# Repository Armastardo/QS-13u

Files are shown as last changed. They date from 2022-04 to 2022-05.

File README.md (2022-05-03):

# QS-13u

Un teclado 40% de 13u, diseñado por Quark.Works, inspirado en el layout del Bacca40.

QS-13u render

## Layouts

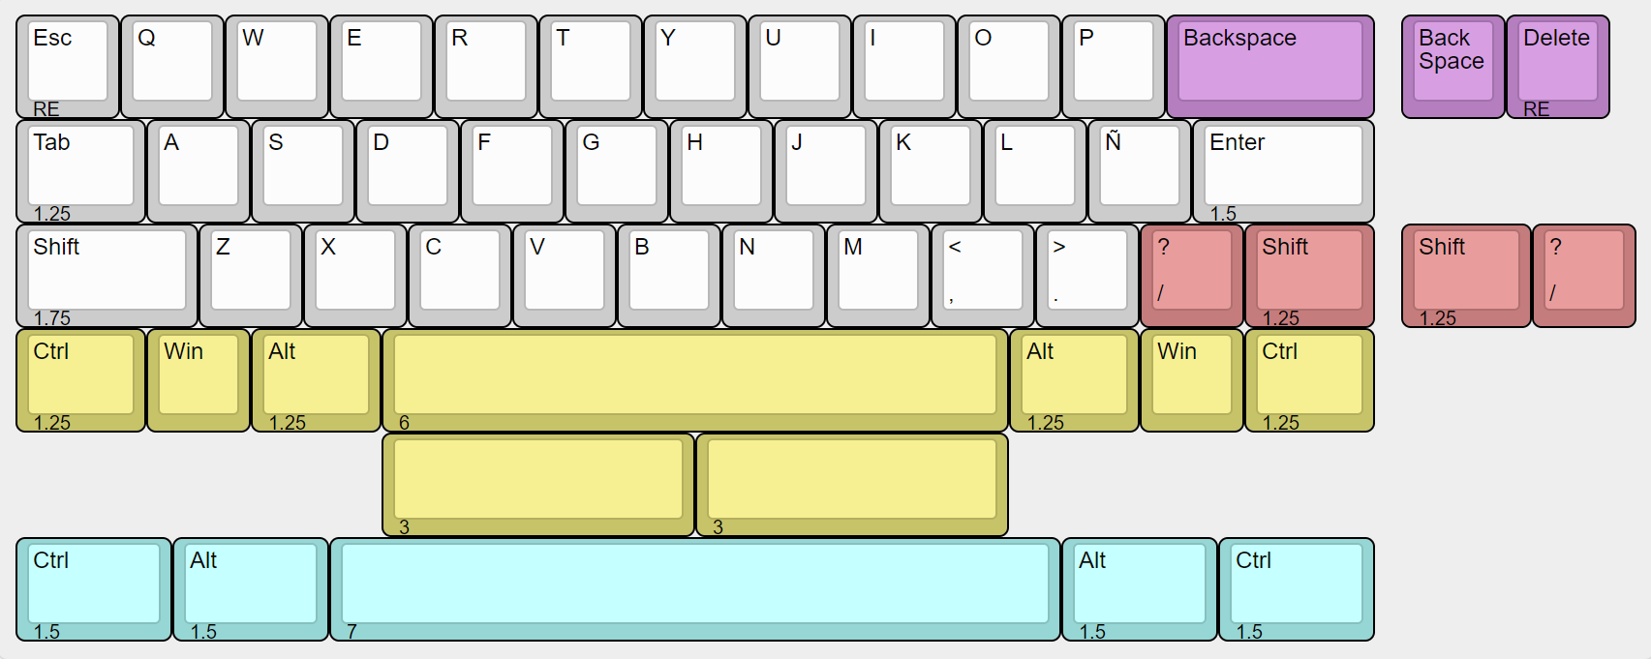
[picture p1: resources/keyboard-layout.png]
QS-13u layouts


[KLE Link](http://www.keyboard-layout-editor.com/#/gists/edd9330d8816866bf59f697946c975f9)

## Case

QS-13u render

QS-13u render

QS-13G (gummy worm)

Pendiente, buscar tamaño de oring adecuado

| Qty | Item						| Notes							|
|----:|---|---|
| 2	| Tornillo M2.5 x 4 mm						| https://www.mcmaster.com/91290A099/		|
| 4	| Tornillo M2.5 x 10 mm					| https://www.mcmaster.com/91290A103/		|
| 1	| XYZ Daughterboard			| https://github.com/xyzz/xyztkl-r2/tree/main/dboard	|

La version heatset ademas utiliza:
https://www.aliexpress.com/item/1005003174906572.html

| Qty | Item						|
|----:|---|
| 2	| Insert M2.5 x 3 x 3.5						|
| 4	| Insert M2.5 x 5 x 3.5					|

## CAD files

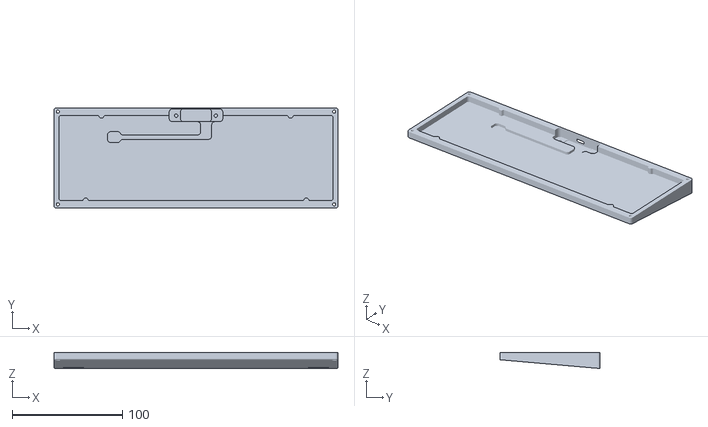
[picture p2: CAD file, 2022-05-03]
case/3d print/QS-13GT bottom heatset.stl
257.6 x 91.2 x 14.5

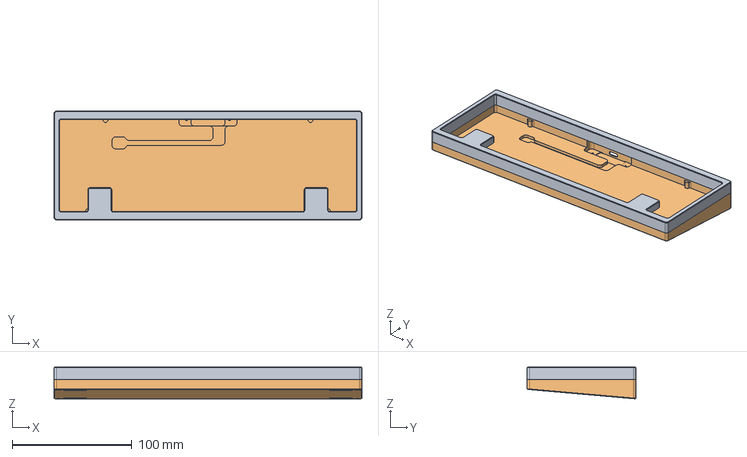
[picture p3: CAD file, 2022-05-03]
case/QS-13G.step
257.6 x 91.2 x 26.5 mm

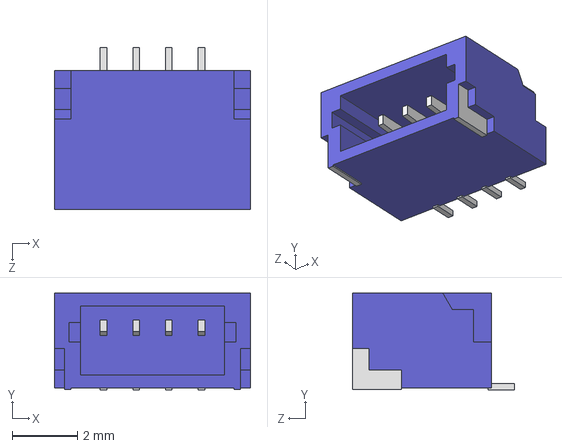
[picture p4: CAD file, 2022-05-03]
pcb/extra/SM04B-SRSS-TB.STEP
6.00 x 2.96 x 4.95 mm

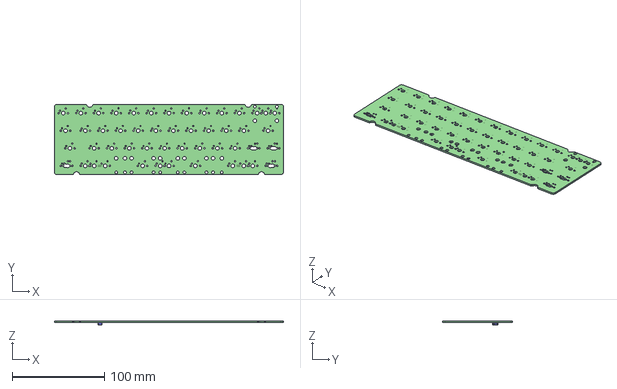
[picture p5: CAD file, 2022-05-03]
pcb/QS-13u-broke.step
247.6 x 76.2 x 4.61 mm
_autosave-QS-13u PCB

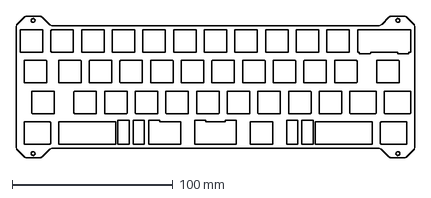
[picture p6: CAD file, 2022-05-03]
plate/QS-13 Top Mount.dxf
247.7 x 88.2 mm

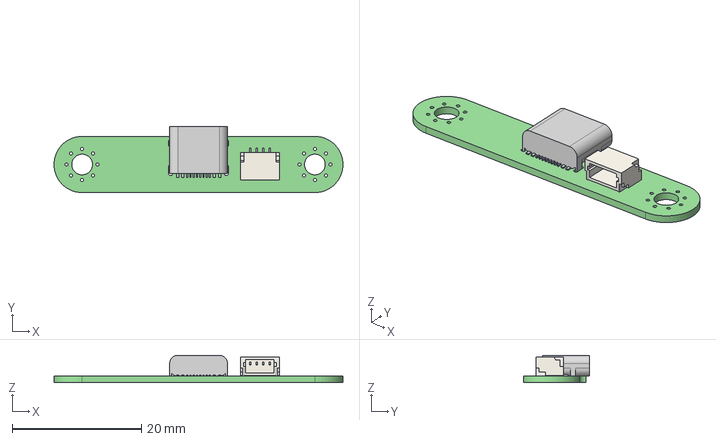
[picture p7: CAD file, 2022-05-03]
resources/xyz-dboard.step
44.7 x 10.3 x 4.23 mm
_autosave-dboard PCB

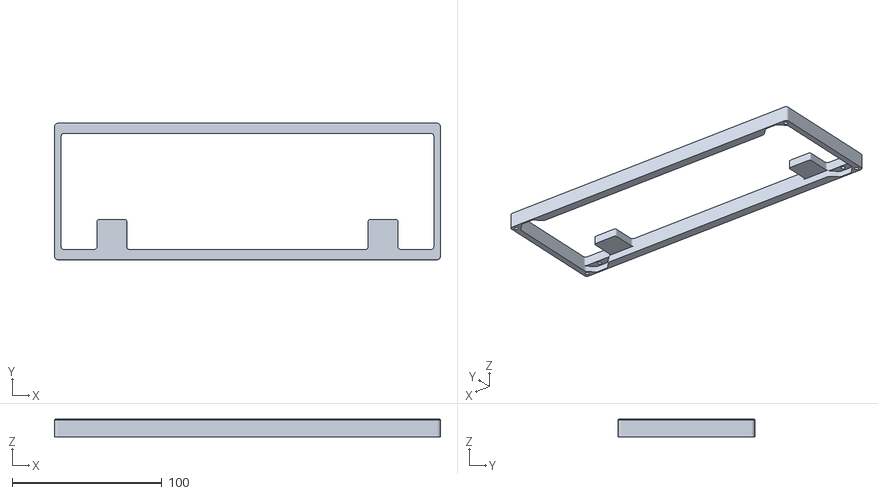
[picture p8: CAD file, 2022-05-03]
case/3d print/QS-13GT top heatset.stl
257.6 x 91.2 x 12.0

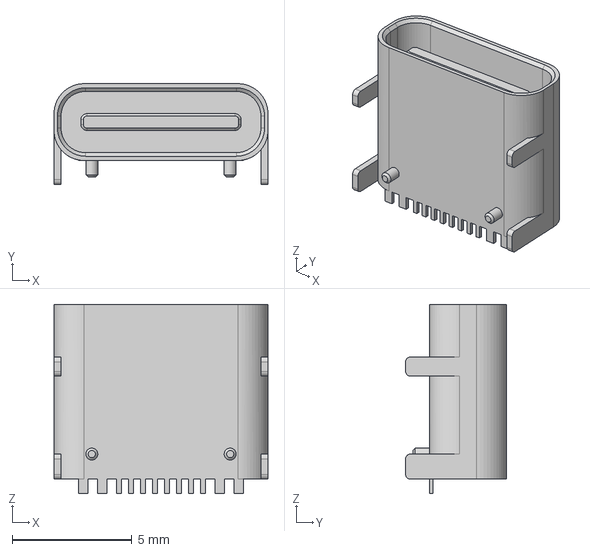
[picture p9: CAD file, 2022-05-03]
pcb/extra/TYPE-C-31-M-12.step
8.94 x 4.21 x 7.90 mm

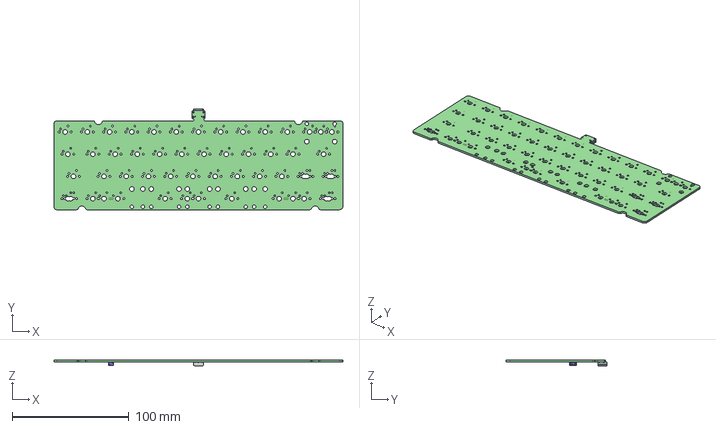
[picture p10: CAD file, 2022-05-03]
pcb/QS-13u.step
247.6 x 86.2 x 4.86 mm
_autosave-QS-13u PCB

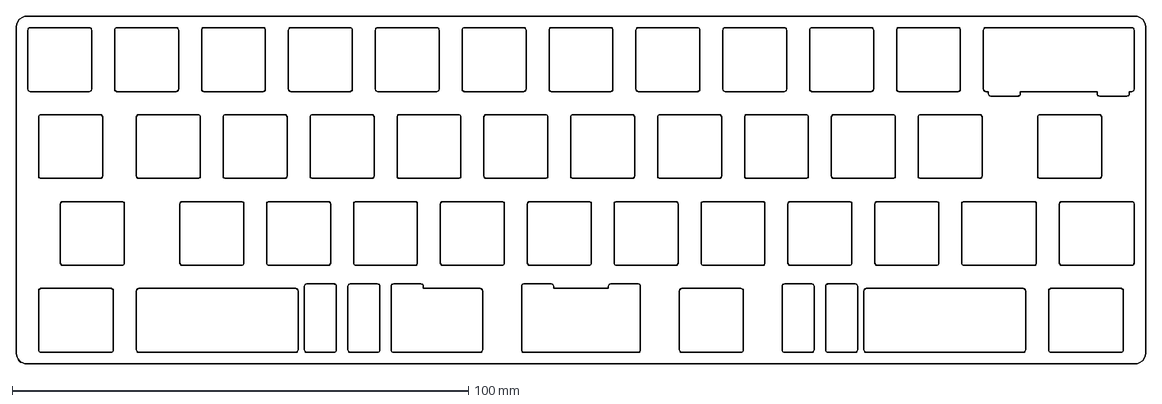
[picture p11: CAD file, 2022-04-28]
plate/QS-13 Gummy.dxf
247.7 x 76.2 mm

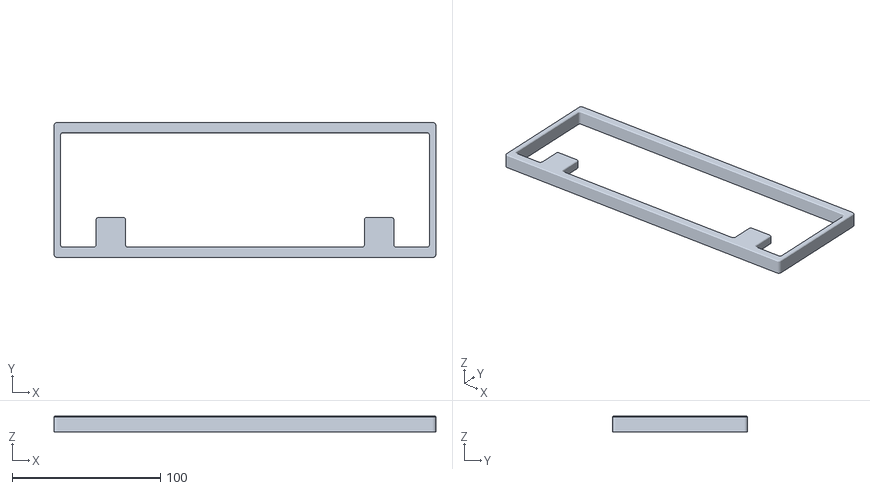
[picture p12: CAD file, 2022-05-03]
case/3d print/QS-13G top heatset.stl
257.6 x 91.2 x 10.5

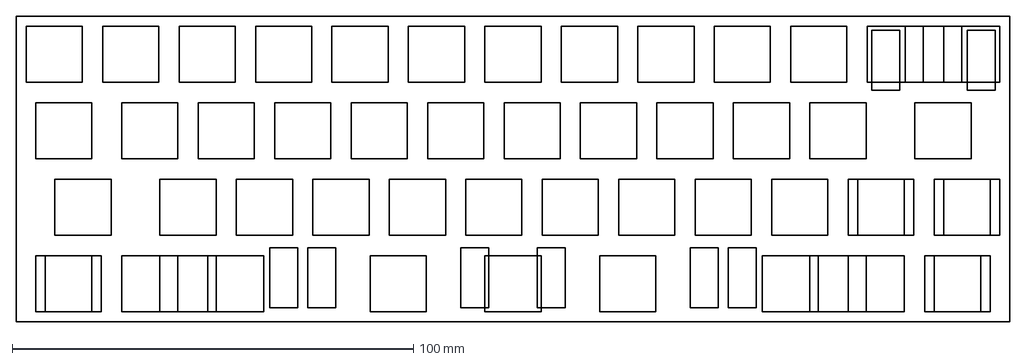
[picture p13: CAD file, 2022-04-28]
plate/QS-13 ai03 plategen.dxf
247.7 x 76.2 mm

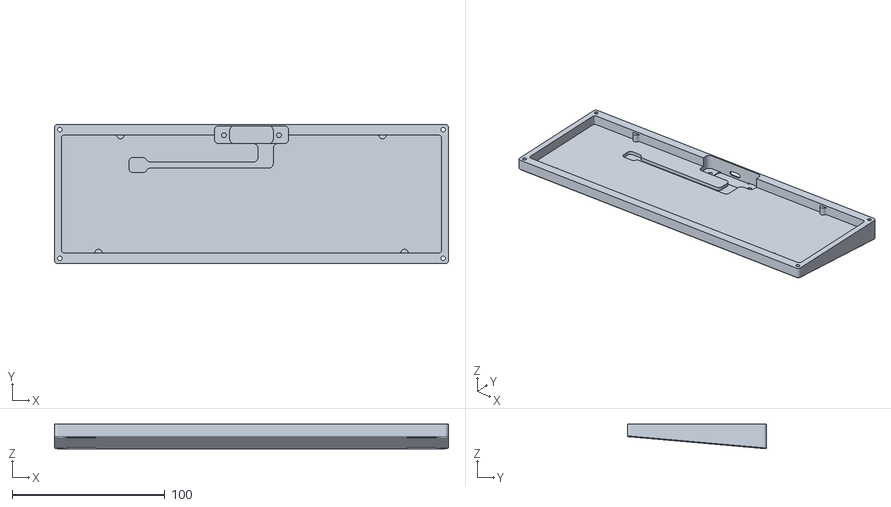
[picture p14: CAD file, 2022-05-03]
case/3d print/QS-13G bottom heatset.stl
257.6 x 91.2 x 16.0

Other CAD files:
case/QS-13GT.step

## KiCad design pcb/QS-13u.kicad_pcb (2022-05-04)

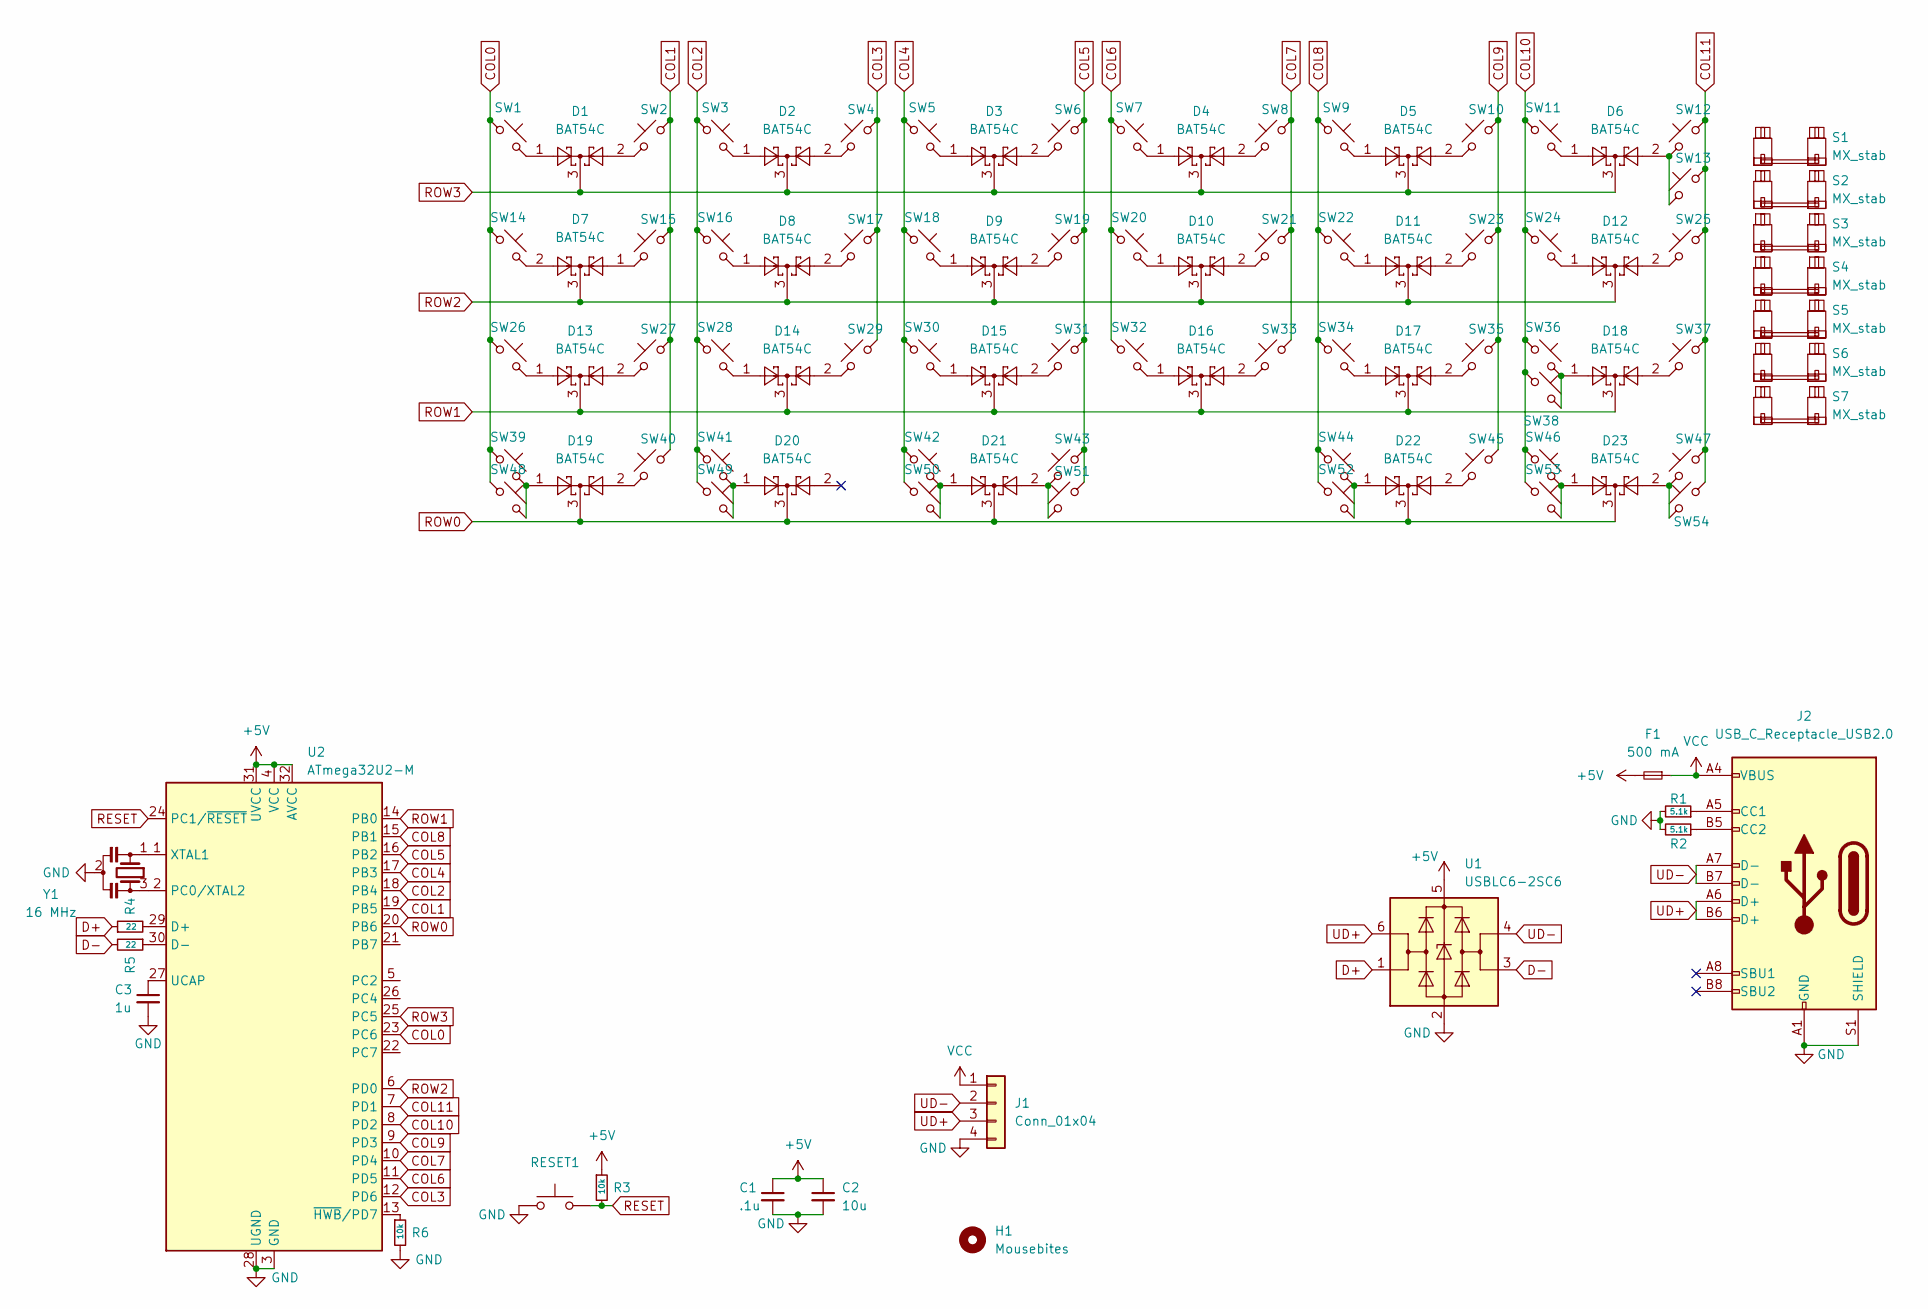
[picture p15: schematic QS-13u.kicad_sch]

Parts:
C1: .1u; C_0603_1608Metric
C2: 10u; C_0603_1608Metric
C3: 1u; C_0603_1608Metric
D1, D2, D3, D4, D5, D6, D7, D8, D9, D10, D11, D12, D13, D14, D15, D16, D17, D18, D19, D20, D21, D22, D23: BAT54C; SOT-23
F1: 500 mA; Fuse_1206_3216Metric
H1: Mousebites
J1: Conn_01x04; JST_SH_SM04B-SRSS-TB_1x04-1MP_P1.00mm_Horizontal
J2: USB_C_Receptacle_USB2.0; USB_C_Receptacle_HRO_TYPE-C-31-M-12
R1, R2: 5.1k; R_0603_1608Metric
R3, R6: 10k; R_0603_1608Metric
R4, R5: 22; R_0603_1608Metric
RESET1: SW_Push; SW_SPST_SKQG_WithStem
S1, S2: MX_stab; STAB_MX_3u
S3, S4, S6: MX_stab; STAB_MX_2u
S5: MX_stab; STAB_MX_6u
S7: MX_stab; STAB_MX_7u
SW1, SW2, SW3, SW4, SW5, SW6, SW7, SW8, SW9, SW10, SW11, SW12, SW13, SW15, SW16, SW17, SW18, SW19, SW20, SW21, SW22, SW23, SW24, SW25, SW27, SW28, SW29, SW30, SW31, SW32, SW33, SW34, SW35, SW38, SW40, SW42, SW43, SW45, SW47, SW50, SW51: MX_SW_solder; SW_MX_1u
SW14, SW36, SW39, SW41, SW44, SW46, SW54: MX_SW_solder; SW_MX_1.25u
SW26, SW37: MX_SW_solder; SW_MX_1.75u
SW48, SW49, SW52, SW53: MX_SW_solder; SW_MX_1.5u
U1: USBLC6-2SC6; SOT-23-6
U2: ATmega32U2-M; QFN-32-1EP_5x5mm_P0.5mm_EP3.1x3.1mm
Y1: 16 MHz; Resonator_SMD_Murata_CSTxExxV-3Pin_3.0x1.1mm

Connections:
+5V: C1.1, C2.1, F1.2, R3.1, U1.5 (VBUS), U2.4 (VCC), U2.31 (UVCC), U2.32 (AVCC)
COL0: SW1.1, SW14.1, SW26.1, SW39.1, SW48.1, U2.23 (PC6)
COL1: SW2.2, SW15.2, SW27.2, SW40.2, U2.19 (PB5)
COL2: SW3.1, SW16.1, SW28.1, SW41.1, SW49.1, U2.18 (PB4)
COL3: SW4.2, SW17.2, SW29.2, U2.12 (PD6)
COL4: SW5.1, SW18.1, SW30.1, SW42.1, SW50.1, U2.17 (PB3)
COL5: SW6.2, SW19.2, SW31.2, SW43.2, SW51.2, U2.16 (PB2)
COL6: SW7.1, SW20.1, SW32.1, U2.11 (PD5)
COL7: SW8.2, SW21.2, SW33.2, U2.10 (PD4)
COL8: SW9.1, SW22.1, SW34.1, SW44.1, SW52.1, U2.15 (PB1)
COL9: SW10.2, SW23.2, SW35.2, SW45.2, U2.9 (PD3)
COL10: SW11.1, SW24.1, SW36.1, SW38.1, SW46.1, SW53.1, U2.8 (PD2)
COL11: SW12.2, SW13.2, SW25.2, SW37.2, SW47.2, SW54.2, U2.7 (PD1)
D+: R4.1, U1.1 (I/O1)
D-: R5.2, U1.3 (I/O2)
GND: C1.2, C2.2, C3.2, J1.4, J2.A1 (GND), J2.A12 (GND), J2.B1 (GND), J2.B12 (GND), J2.S1 (SHIELD), R1.2, R2.2, R6.2, RESET1.1, U1.2 (GND), U2.3 (GND), U2.28 (UGND), U2.33 (GND), Y1.2
unnamed: C3.1, U2.27 (UCAP)
unnamed: D1.1, SW1.2
unnamed: D1.2, SW2.1
unnamed: D2.1, SW3.2
unnamed: D2.2, SW4.1
unnamed: D3.1, SW5.2
unnamed: D3.2, SW6.1
unnamed: D4.1, SW7.2
unnamed: D4.2, SW8.1
unnamed: D5.1, SW9.2
unnamed: D5.2, SW10.1
unnamed: D6.1, SW11.2
unnamed: D6.2, SW12.1, SW13.1
unnamed: D7.1, SW15.1
unnamed: D7.2, SW14.2
unnamed: D8.1, SW16.2
unnamed: D8.2, SW17.1
unnamed: D9.1, SW18.2
unnamed: D9.2, SW19.1
unnamed: D10.1, SW20.2
unnamed: D10.2, SW21.1
unnamed: D11.1, SW22.2
unnamed: D11.2, SW23.1
unnamed: D12.1, SW24.2
unnamed: D12.2, SW25.1
unnamed: D13.1, SW26.2
unnamed: D13.2, SW27.1
unnamed: D14.1, SW28.2
unnamed: D14.2, SW29.1
unnamed: D15.1, SW30.2
unnamed: D15.2, SW31.1
unnamed: D16.1, SW32.2
unnamed: D16.2, SW33.1
unnamed: D17.1, SW34.2
unnamed: D17.2, SW35.1
unnamed: D18.1, SW36.2, SW38.2
unnamed: D18.2, SW37.1
unnamed: D19.1, SW39.2, SW48.2
unnamed: D19.2, SW40.1
unnamed: D20.1, SW41.2, SW49.2
unnamed: D21.1, SW42.2, SW50.2
unnamed: D21.2, SW43.1, SW51.1
unnamed: D22.1, SW44.2, SW52.2
unnamed: D22.2, SW45.1
unnamed: D23.1, SW46.2, SW53.2
unnamed: D23.2, SW47.1, SW54.1
unnamed: J2.A5 (CC1), R1.1
unnamed: J2.B5 (CC2), R2.1
unnamed: R4.2, U2.29 (D+)
unnamed: R5.1, U2.30 (D-)
unnamed: R6.1, U2.13 (~HWB/PD7)
unnamed: U2.1 (XTAL1), Y1.1
unnamed: U2.2 (PC0/XTAL2), Y1.3
RESET: R3.2, RESET1.2, U2.24 (PC1/~RESET)
ROW0: D19.3, D20.3, D21.3, D22.3, D23.3, U2.20 (PB6)
ROW1: D13.3, D14.3, D15.3, D16.3, D17.3, D18.3, U2.14 (PB0)
ROW2: D7.3, D8.3, D9.3, D10.3, D11.3, D12.3, U2.6 (PD0)
ROW3: D1.3, D2.3, D3.3, D4.3, D5.3, D6.3, U2.25 (PC5)
UD+: J1.3, J2.A6 (D+), J2.B6 (D+), U1.6 (I/O1)
UD-: J1.2, J2.A7 (D-), J2.B7 (D-), U1.4 (I/O2)
VCC: F1.1, J1.1, J2.A4 (VBUS), J2.A9 (VBUS), J2.B4 (VBUS), J2.B9 (VBUS)

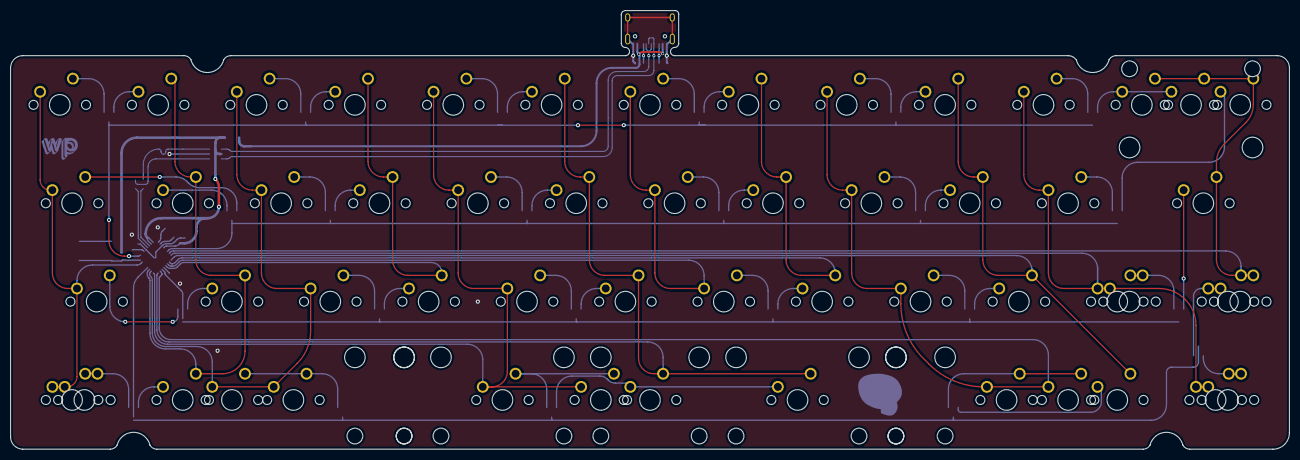
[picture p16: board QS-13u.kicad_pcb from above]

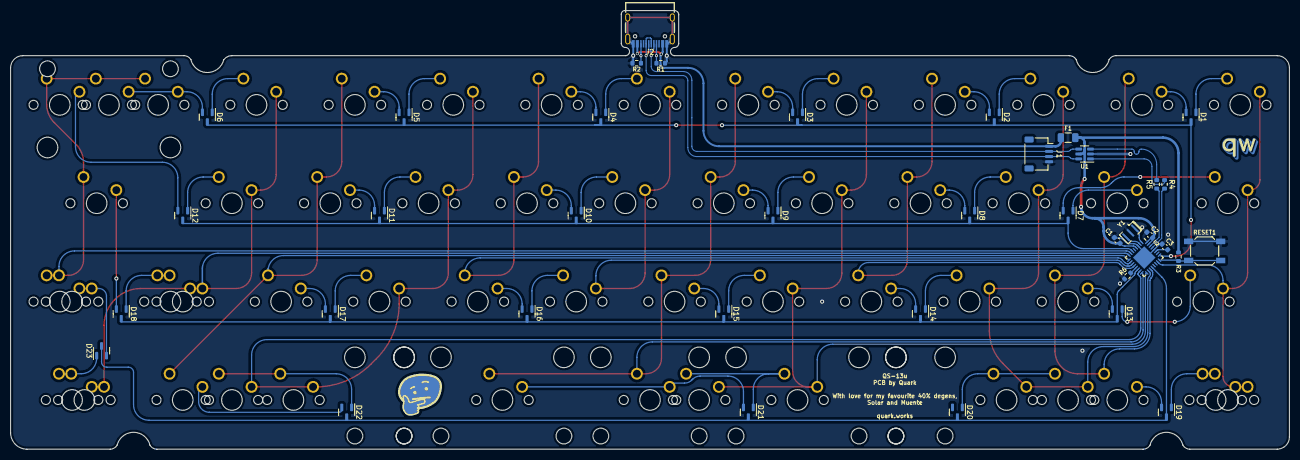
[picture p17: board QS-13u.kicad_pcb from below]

Board: 2 copper layers, 247.6 x 84.9 mm, 102 parts (41 on the bottom side), 77 nets.

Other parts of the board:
Ref**: Val**; thinking
Ref**#2: Val**; qw-logo-small

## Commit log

2022-04-27 Initial commit. TODO routing
    [QS-13u.kicad_pcb, QS-13u.kicad_sch]
2022-04-27 gummy worm case, plate
    [QS-13 Gummy.dxf, QS-13 ai03 plategen.dxf, QS-13G.step]
2022-04-28 Undocumented progress
    [QS-13u.kicad_sch]
2022-04-28 Moved PCB to pcb folder
    [QS-13u.kicad_pcb, QS-13u.kicad_sch]
2022-04-28 .... actually moved. IDK what tf happened
    [QS-13u.kicad_pcb, QS-13u.kicad_sch]
2022-04-28 Fixes + Updates
    - Fixed some weird submodules shenanigans
    - Repositioned the JST connector
    - Adjusted the outline for gummy o-ring mount
    [QS-13u.kicad_pcb, QS-13u.kicad_sch]
2022-04-28 USB Port + DB Routed
    [QS-13u.kicad_pcb, QS-13u.kicad_sch]
2022-04-28 extra step models
    [QS-13u.kicad_pcb, SM04B-SRSS-TB.STEP, TYPE-C-31-M-12.step]
2022-04-28 output pcb 3d models
    [QS-13u-broke.step, QS-13u.step]
2022-04-28 updated case files
    [QS-13G bottom.stl, QS-13G top.stl, QS-13G.step]
2022-04-28 fixed jst channel
    [QS-13G bottom.stl, QS-13G.step]
2022-04-28 Redesign with xyz db, heatset 3d print version and m2.5 screws
    [QS-13G bottom heatset.stl, QS-13G bottom.stl, QS-13G top heatset.stl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]
2022-04-29 top mount version
    [QS-13 Top Mount.dxf, QS-13GT bottom heatset.stl, QS-13GT top heatset.stl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]
2022-05-04 PCB Rev.1
    Everything seems to be connected and no obvious errors were found
    [QS-13u-B_Cu.gbr, QS-13u-B_Mask.gbr, QS-13u-B_Paste.gbr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]
2022-05-04 Added art and adjusted gerbers
    [QS-13u-B_Cu.gbr, QS-13u-B_Mask.gbr, QS-13u-B_Paste.gbr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]
2022-05-04 Afmuente -> Muente
    [QS-13u-B_Cu.gbr, QS-13u-B_Mask.gbr, QS-13u-B_Paste.gbr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]
2022-06-30 Added thinking svg and kicad footprint
